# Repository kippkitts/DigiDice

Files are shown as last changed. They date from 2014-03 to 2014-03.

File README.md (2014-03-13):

DigiDice
========



DigiDice is a random number generator that simulates a 4, 6, 8, 10, 12, and 20 sided die.  There are six buttons, each corresponding to one of these dice, and pressing one of these buttons will generate a true random number within the selected die's range.  That number is then shown on a 2 digit 7 segment display.

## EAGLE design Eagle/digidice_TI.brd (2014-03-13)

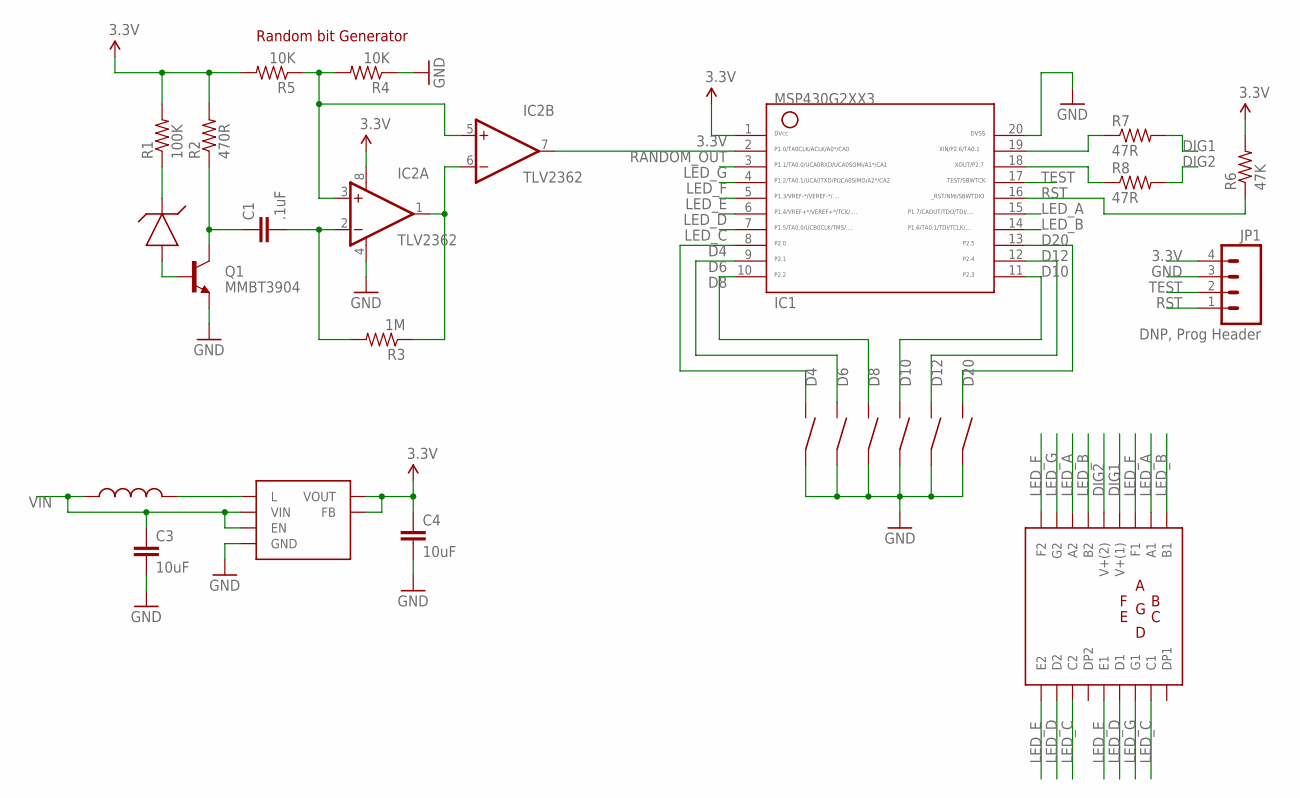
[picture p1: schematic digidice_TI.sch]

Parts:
C1: .1uF; 0402-CAP
C3, C4: 10uF; 0603-CAP
IC1: MSP430G2203IPW20; PW20
IC2: TLV2362; MSOP08; MPN OPA2340EA/250
IC3: TLV61225; SOT-363
JP1: DNP, Prog Header; 1X04-1.27MM
L1: PFL2015-472ML; COILCRAFT-PFL2015
Q1: MMBT3904; SOT23
R1: 100K; 0402-RES
R2: 470R; 0402-RES
R3: 1M; 0402-RES
R4, R5: 10K; 0402-RES
R6: 47K; 0402-RES
R7, R8: 47R; 0805
SW1, SW2, SW3, SW4, SW5, SW6: SPST_SWITCH; EG2513-ND
U$1: ZXRE1004FFTA; SOT23
U$2: 2DIGIT_7SEGMENT; HDSP-521E

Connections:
3.3V: C4.1, IC1.1, IC2.8 (V+), IC3.P$2 (FB), IC3.P$4 (VOUT), JP1.4, R1.2, R2.2, R5.2, R6.2
D4: IC1.8, SW6.P$2 (2)
D6: IC1.9, SW5.P$2 (2)
D8: IC1.10, SW4.P$2 (2)
D10: IC1.11, SW3.P$2 (2)
D12: IC1.12, SW2.P$2 (2)
D20: IC1.13, SW1.P$2 (2)
DIG1: R7.2, U$2.P$13 (V+(1))
DIG2: R8.2, U$2.P$14 (V+(2))
GND: C3.2, C4.2, IC1.20, IC2.4 (V-), IC3.P$3 (GND), JP1.3, Q1.2 (E), R4.1, SW1.P$1 (1), SW2.P$1 (1), SW3.P$1 (1), SW4.P$1 (1), SW5.P$1 (1), SW6.P$1 (1)
LED_A: IC1.15, U$2.P$11 (A1), U$2.P$16 (A2)
LED_B: IC1.14, U$2.P$10 (B1), U$2.P$15 (B2)
LED_C: IC1.7, U$2.P$3 (C2), U$2.P$8 (C1)
LED_D: IC1.6, U$2.P$2 (D2), U$2.P$6 (D1)
LED_E: IC1.5, U$2.P$1 (E2), U$2.P$5 (E1)
LED_F: IC1.4, U$2.P$12 (F1), U$2.P$18 (F2)
LED_G: IC1.3, U$2.P$7 (G1), U$2.P$17 (G2)
unnamed: Q1.1 (B), U$1.2 (A)
unnamed: C1.1, Q1.3 (C), R2.1
unnamed: R1.1, U$1.1 (K)
unnamed: C1.2, IC2.2 (-IN), R3.2
unnamed: IC2.1 (OUT), IC2.6 (-IN), R3.1
unnamed: IC2.3 (+IN), IC2.5 (+IN), R4.2, R5.1
unnamed: IC1.19, R7.1
unnamed: IC1.18, R8.1
unnamed: IC3.P$5 (L), L1.P$2 (2)
RANDOM_OUT: IC1.2, IC2.7 (OUT)
RST: IC1.16, JP1.1, R6.1
TEST: IC1.17, JP1.2
VIN: C3.1, IC3.P$1 (VIN), IC3.P$6 (EN), L1.P$1 (1)

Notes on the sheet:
Random bit Generator

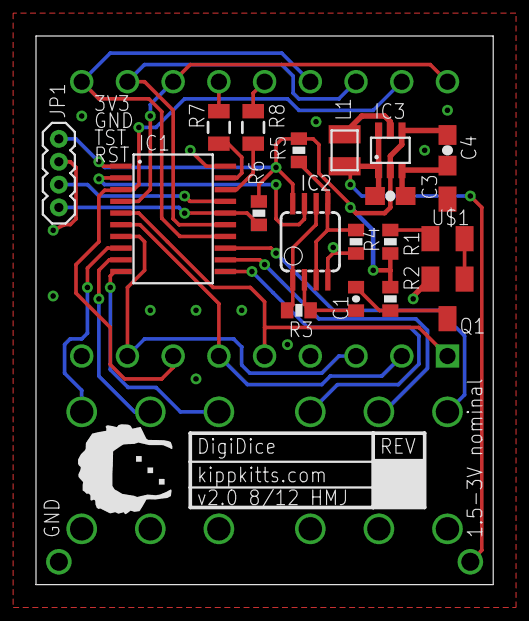
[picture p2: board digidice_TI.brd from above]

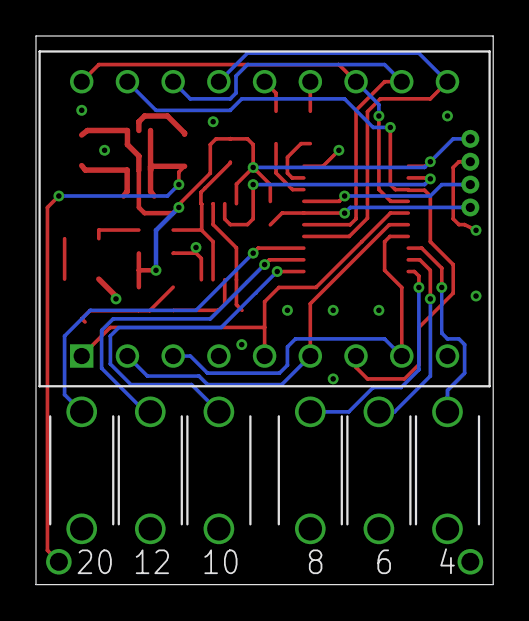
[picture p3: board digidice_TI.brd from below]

Board: 2 copper layers, 25.4 x 30.5 mm, 26 parts (7 on the bottom side), 30 nets.

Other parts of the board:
U$3: TOP_DOCU_5MM

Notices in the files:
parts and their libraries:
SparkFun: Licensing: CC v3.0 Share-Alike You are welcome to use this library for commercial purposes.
